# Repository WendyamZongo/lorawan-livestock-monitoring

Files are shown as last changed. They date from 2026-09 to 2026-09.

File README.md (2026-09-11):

# LoRaWAN Livestock Health and Location Monitoring System

An end-to-end LoRaWAN system for monitoring cattle body temperature and location, covering the ear-tag sensor node, the radio link, the gateway, and a real-time web dashboard.

The system is designed for extensive grazing conditions, where animals are dispersed over large areas with no cellular coverage and no mains power, and where a herder cannot practically inspect every animal every day. Early detection of a temperature anomaly and knowledge of an animal's position are the two pieces of information that matter most in that setting.

**Status:** functional prototype. All four subsystems are implemented and working end to end. See Limitations for what is not yet in place.

---
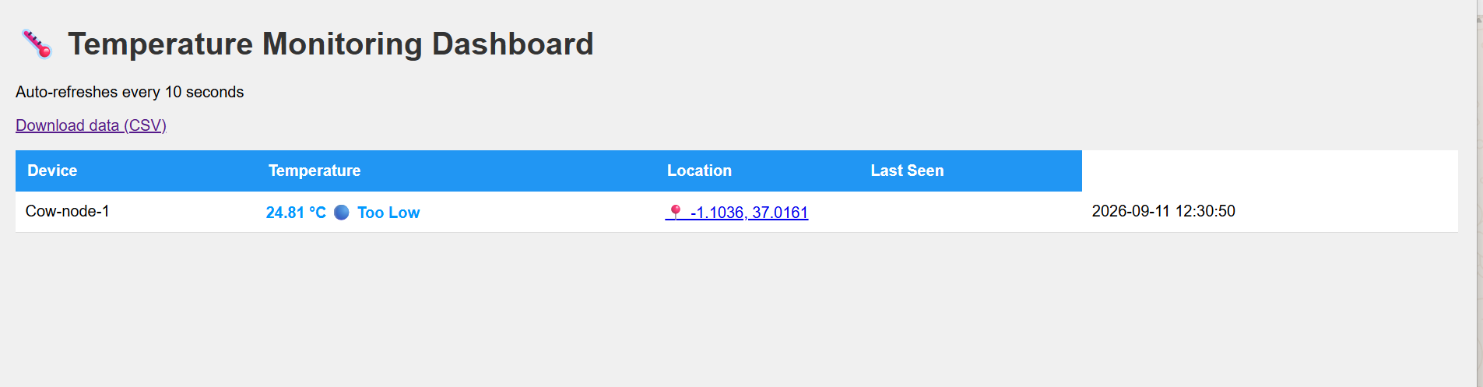
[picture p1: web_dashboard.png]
Dashboard


*Real-time herd monitoring dashboard*

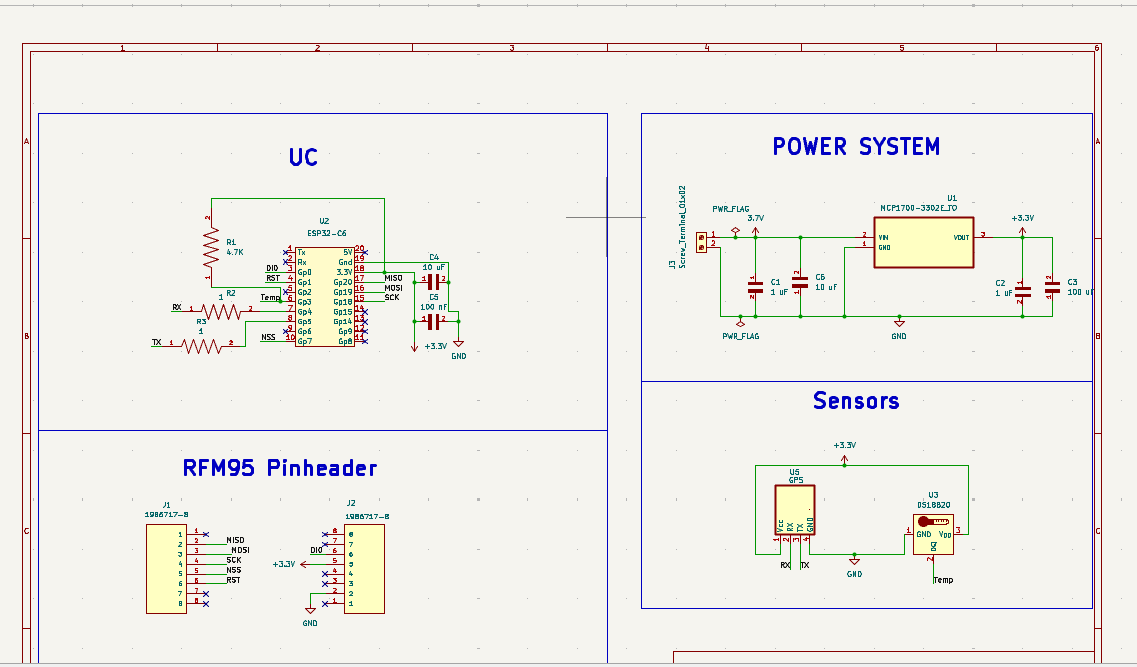
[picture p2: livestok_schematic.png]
Schematic


*Ear tag node schematic*

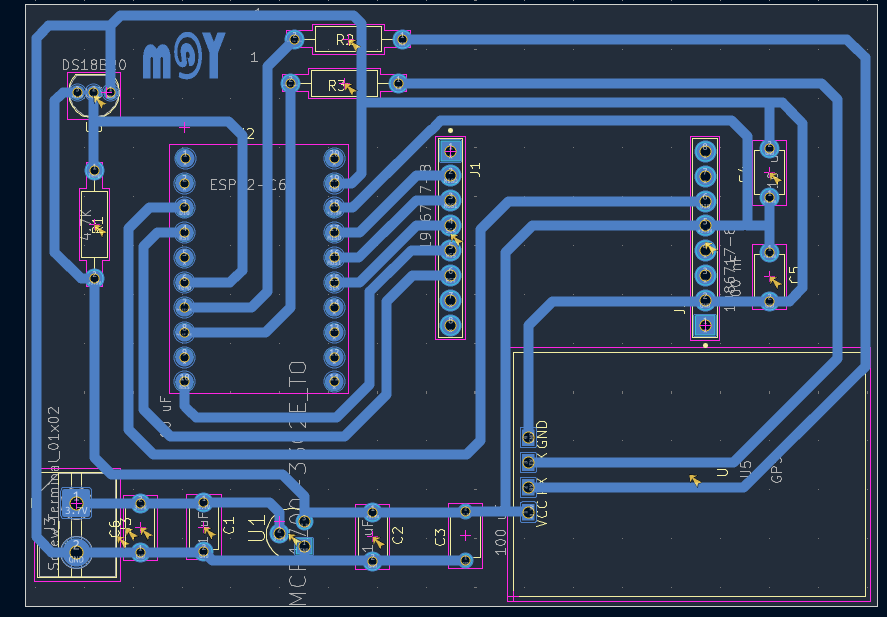
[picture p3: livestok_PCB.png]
PCB


*Ear tag node PCB layout*

## System architecture

```
  Ear tag node                    Gateway                    Server
  ------------                    -------                    ------
  ESP32-C6                                                   ChirpStack
  DS18B20  (temperature)   -->    RAK5146 PiHAT       -->    (self-hosted)
  NEO-6M   (GNSS)                 Raspberry Pi                    |
  RFM95W   (LoRa)                                             MQTT
  12,000 mAh Li-ion                                               |
                                                                  v
         LoRaWAN uplink, 4x per day                        Flask dashboard
                                                            + CSV logging
```

---

## Ear tag node

Battery-powered sensor node worn as an ear tag.

| Function | Part |
|---|---|
| MCU | ESP32-C6 |
| Body temperature | DS18B20 (1-Wire) |
| Localisation | u-blox NEO-6M GNSS |
| Radio | RFM95W (LoRa, 868 MHz, SF7) |
| Power | Single 12,000 mAh 3.7 V Li-ion cell |

Firmware is written in C++ using the Arduino framework.

The LoRaWAN ABP uplink path is implemented directly in the firmware, including AES-128 payload encryption and the CMAC-based message integrity check, rather than through a LoRaWAN stack library. This was done to work through the MAC layer explicitly. A production build would use an audited implementation.

### Operating cycle

The node spends almost all of its life in deep sleep. Four times per day it wakes, reads body temperature, acquires a GNSS fix, transmits a single LoRaWAN uplink, and returns to sleep.

Deep sleep on the ESP32-C6 clears RAM and restarts execution from the top, so the entire measurement cycle runs in `setup()` and `loop()` is unused. The LoRaWAN frame counter is held in RTC memory so that it survives sleep; without this the network server would reject every uplink as a replay.

The GNSS receiver is placed in UBX backup mode before sleeping rather than left running. Fix acquisition is bounded by a timeout, and the payload carries a validity flag so the decoder can distinguish a real position from a cycle that ended without a fix. A node under heavy tree cover therefore still reports its temperature instead of draining the cell waiting for satellites.

### Temperature interpretation

The dashboard currently classifies each reading against fixed thresholds: below 35 °C, normal to 38.5 °C, warning to 39.5 °C, and fever above that.

These thresholds are a placeholder, and the limits of the approach are worth stating. The DS18B20 is specified at ±0.5 °C, and an ear tag measures at a site exposed to solar radiation and wind. A fixed cut-off will therefore raise false fever alerts on a hot afternoon and miss real ones at night.

The intended replacement is alerting on sustained deviation from each animal's own baseline, which absorbs both the sensor offset and the individual animal. That logic is not yet implemented.

### Power budget

Sizing assumptions for the 12,000 mAh cell:

| Item | Estimate |
|---|---|
| GNSS fix | ~30 mA for 30 s per cycle |
| LoRa transmit (SF7, 24-byte frame) | ~100 mA for ~60 ms per cycle |
| Sensing and processing | ~40 mA for a few seconds per cycle |
| Deep sleep | board-level quiescent current |
| Cycles per day | 4 |

Transmission is negligible in this budget; the GNSS fix dominates the active cycle. Four cycles per day therefore consume only a few mAh, and on these assumptions the node supports well over two years of operation.

The dominant unknown is board-level quiescent current, not the active cycle. Measuring true sleep current on the assembled board is the single most useful validation step for this figure.

---

## Custom PCB

KiCad design files for the node, including the RFM95W transceiver front-end.

RF layout was the main constraint: ground plane continuity under the transceiver, trace impedance on the antenna feed, antenna placement relative to the enclosure and to the animal's body, and supply decoupling close to the module. The antenna is a soldered helical spring rather than a connectorised u.FL or SMA part, so its position is fixed at assembly and had to be planned around the rest of the layout.

A separate RFM95W breakout board was also designed and fabricated to adapt the module's 2 mm pin pitch to a standard 2.54 mm grid, for bench prototyping and node integration. It carries the module and its pin headers only, and is supplied with regulated 3.3 V from the host board.

Files are in `hardware/`.

---

## Gateway

- **RAK5146 PiHAT Kit** on a Raspberry Pi
- Forwards LoRaWAN uplinks to the network server

Configuration notes are in `gateway/`.

---

## Network server

**ChirpStack**, self-hosted. Handles device provisioning, session keys, deduplication of uplinks received by multiple gateways, and payload decoding.

The device payload decoder is in `chirpstack/`. The uplink carries body temperature, latitude, longitude, and a GNSS validity flag.

---

## Web application

A **Python / Flask** application subscribes to the ChirpStack MQTT broker on the uplink topic for the application, decodes each event, and serves a dashboard showing every device with its latest temperature, its last known position as a Google Maps link, and the time it was last heard from. The page refreshes on a timer, and temperature values are colour-coded by band.

Every uplink is appended to a CSV file, which is the historical record and the export path for offline analysis.

Source is in `webapp/`.

---

## Repository layout

```
firmware/
  Cow_monitoring.ino  ESP32-C6 node firmware (Arduino)
  secrets.h.example   template for LoRaWAN session keys
hardware/
  node/               KiCad schematic and PCB for the ear tag node
  rfm95-breakout/     KiCad files for the RFM95W pitch-adapter board
gateway/              Raspberry Pi + RAK5146 configuration
chirpstack/           payload decoder and device profile
webapp/               Flask dashboard and MQTT subscriber
```

Real LoRaWAN session keys live in `firmware/secrets.h`, which is gitignored. Copy `secrets.h.example` and fill in your own device keys from ChirpStack before flashing.

---

## Limitations

Stated plainly, because they matter to anyone considering this work.

- **Fixed temperature thresholds.** Alerting uses absolute cut-offs rather than a per-animal baseline, which is not adequate for an ear-tag measurement site. See Temperature interpretation above.
- **No database.** History lives in a CSV file. The dashboard itself holds only the latest reading per device in memory, so it is blank after a restart until the next uplink arrives, which may be six hours away.
- **No field validation against a reference.** Temperature readings have not been validated against a rectal or ruminal reference measurement on live animals, which is the standard against which any livestock temperature system must eventually be judged.
- **Battery life is calculated, not measured.** The two-year figure follows from the power budget above. It has not been confirmed by long-duration testing, and board-level sleep current has not yet been measured directly.
- **Hand-rolled cryptography.** The AES-128 and CMAC implementations are the author's own and have not been independently audited. They are appropriate for a prototype, not for a deployed product.
- **NEO-6M cold start.** The module is an older generation with slow cold-start acquisition. Retaining almanac data across wake cycles would reduce time to fix and further improve the energy margin.
- **Single-tag testing.** The system has not been exercised with a herd-scale number of nodes, so airtime contention and duty-cycle behaviour at scale remain untested.

---

## Next steps

- Measure board-level quiescent current and confirm the energy budget empirically
- Replace fixed thresholds with per-animal baseline tracking and deviation-based alerting
- Move from CSV to a time-series database, and reload the dashboard state on restart
- Validate temperature against a reference measurement on live animals
- Test with multiple nodes to characterise airtime and collision behaviour

---

## Author

Wendyam Clovis Dubois Zongo
MSc Electrical Engineering (Computer Engineering), PAUSTI / JKUAT, Nairobi
Embedded systems and FPGA engineer

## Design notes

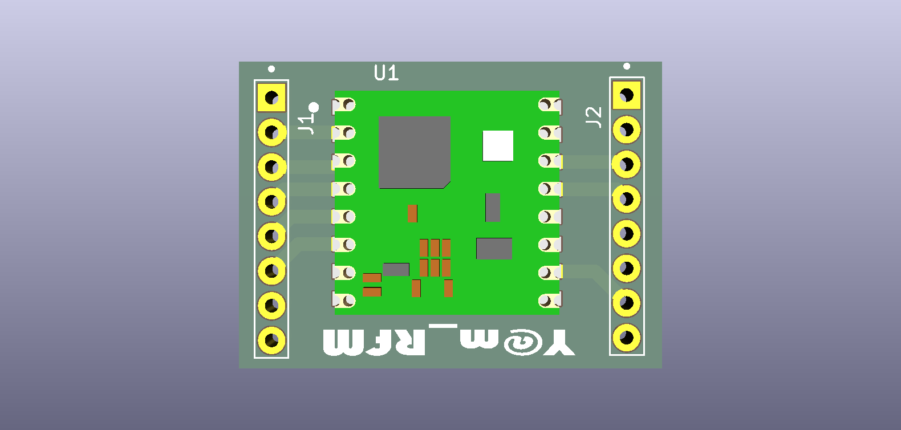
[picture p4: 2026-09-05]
hardware/RFM /RFM0.1.png

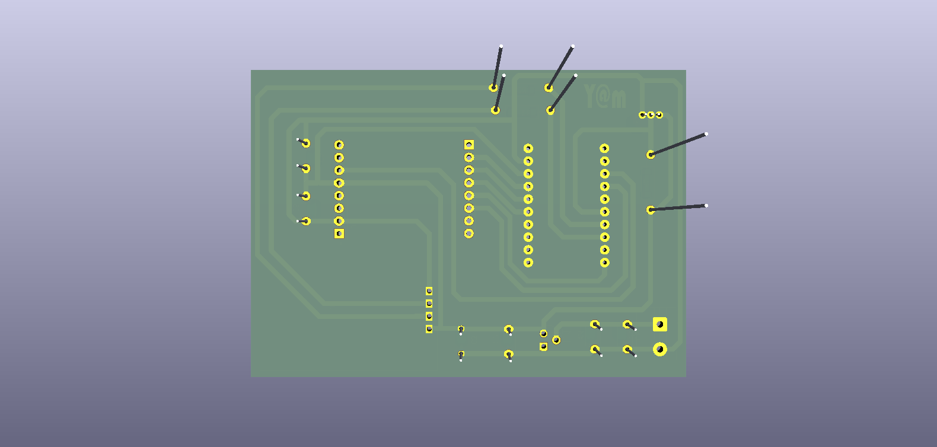
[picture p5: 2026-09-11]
livestok_.png

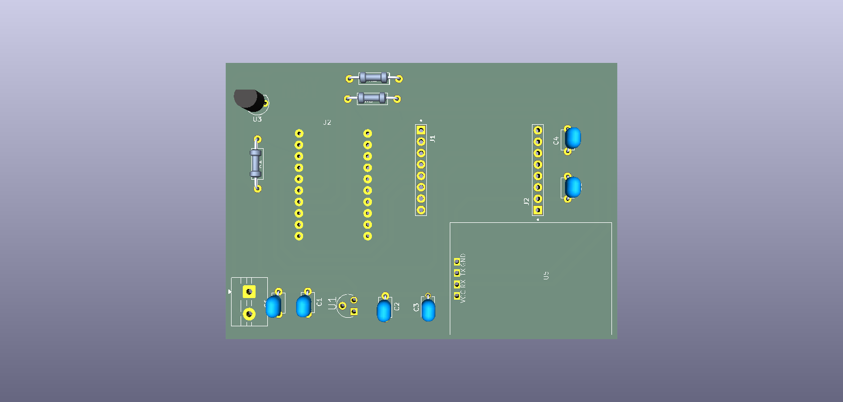
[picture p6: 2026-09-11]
livestok.png

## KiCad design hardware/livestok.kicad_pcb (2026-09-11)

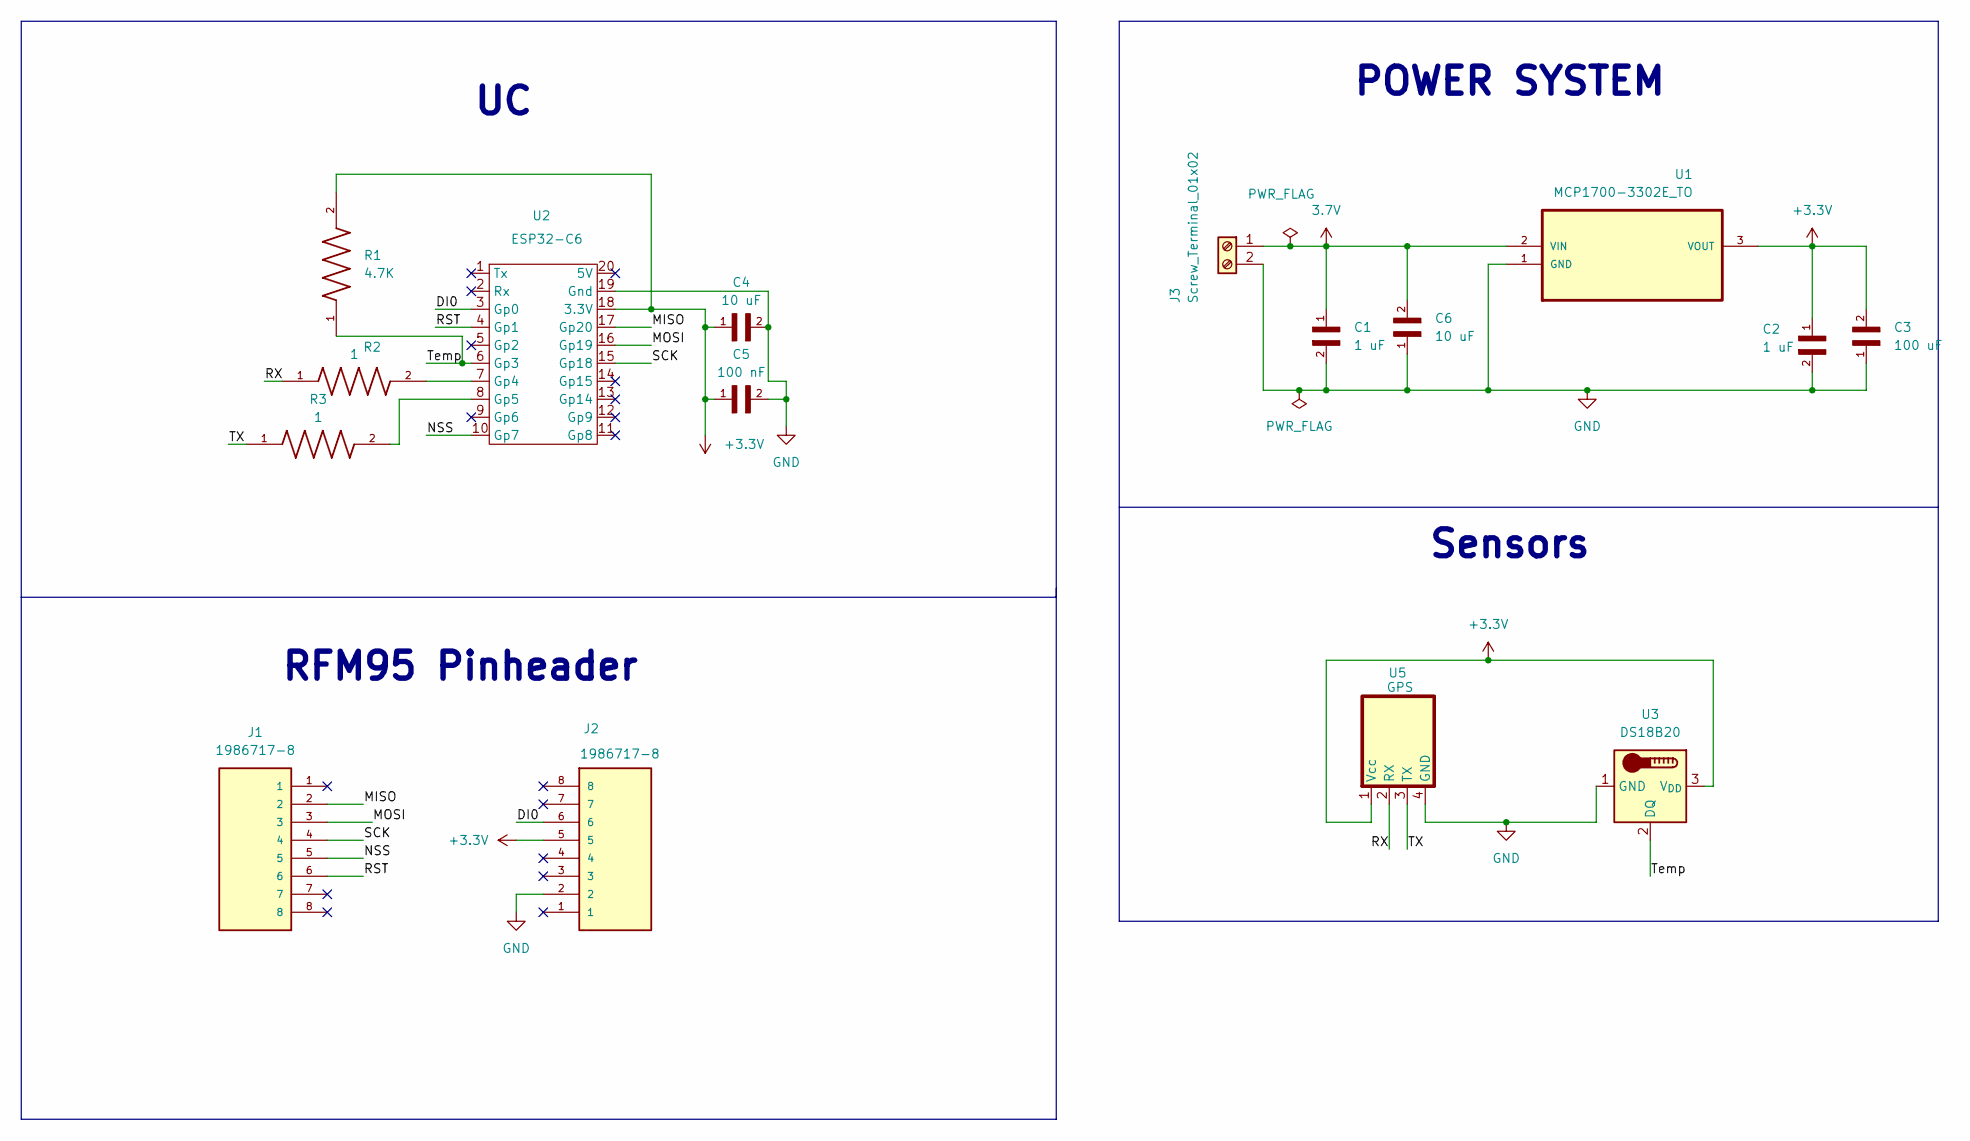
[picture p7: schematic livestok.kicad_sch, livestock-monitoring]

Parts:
C1, C2: 1 uF; CAPRB500W50L450T300H550; PARTREV 20200310
C3: 100 uF; CAPRB500W50L450T300H550; PARTREV 20200310
C4, C6: 10 uF; CAPRB500W50L450T300H550; PARTREV 20200310
C5: 100 nF; CAPRB500W50L450T300H550; PARTREV 20200310
J1, J2: 1986717-8; TE_826629-8; PARTREV R
J3: Screw_Terminal_01x02; TerminalBlock_MaiXu_MX126-5.0-02P_1x02_P5.00mm
R1: 4.7K; RESAD1100W55L680D260; PARTREV 201304
R2, R3: 1; RESAD1100W55L680D260; PARTREV 201304
U1: MCP1700-3302E_TO; TO127P254X495-3; MPN MCP1700-3302E/TO
U2: ESP32-C6; C6-mini
U3: DS18B20; TO-92_Inline
U5: GPS; Gps_Yam

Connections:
3.7V: C1.1, C6.2, J3.1, U1.2 (VIN)
+3.3V: C2.1, C3.2, C4.1, C5.1, J2.5, R1.2, U1.3 (VOUT), U2.18 (3.3V), U3.3 (V_{DD}), U5.1 (Vcc)
/DI0: J2.6, U2.3 (Gp0)
/MISO: J1.2, U2.17 (Gp20)
/MOSI: J1.3, U2.16 (Gp19)
/NSS: J1.5, U2.10 (Gp7)
/RST: J1.6, U2.4 (Gp1)
/RX: R2.1, U5.2 (RX)
/SCK: J1.4, U2.15 (Gp18)
/TX: R3.1, U5.3 (TX)
/Temp: R1.1, U2.6 (Gp3), U3.2 (DQ)
GND: C1.2, C2.2, C3.1, C4.2, C5.2, C6.1, J2.2, J3.2, U1.1 (GND), U2.19 (Gnd), U3.1 (GND), U5.4 (GND)
unnamed: R2.2, U2.7 (Gp4)
unnamed: R3.2, U2.8 (Gp5)

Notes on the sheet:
RFM95 Pinheader
POWER SYSTEM
Sensors

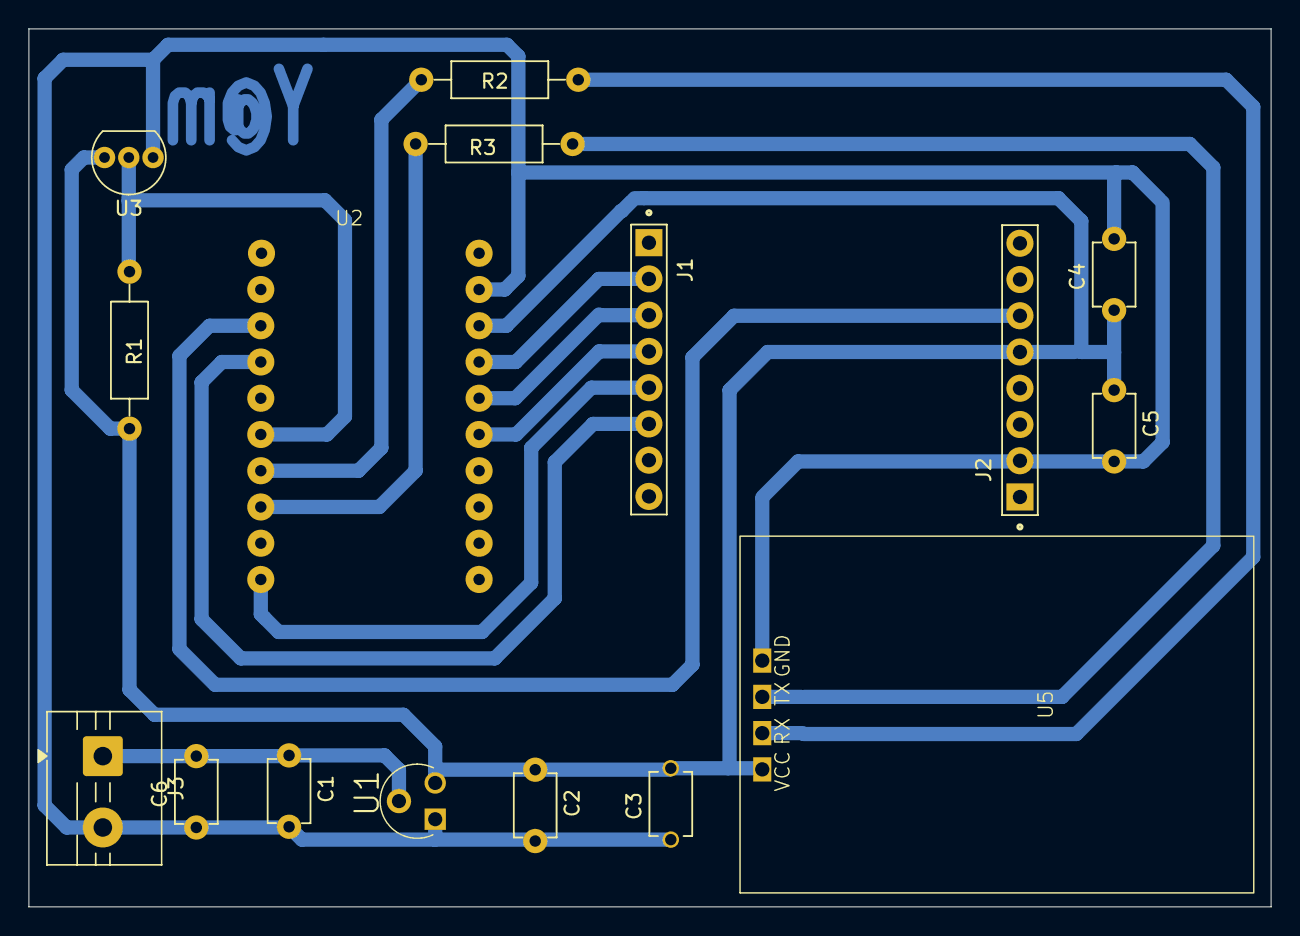
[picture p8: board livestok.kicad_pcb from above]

Board: 2 copper layers, 87.1 x 61.5 mm, 16 parts (0 on the bottom side), 14 nets.

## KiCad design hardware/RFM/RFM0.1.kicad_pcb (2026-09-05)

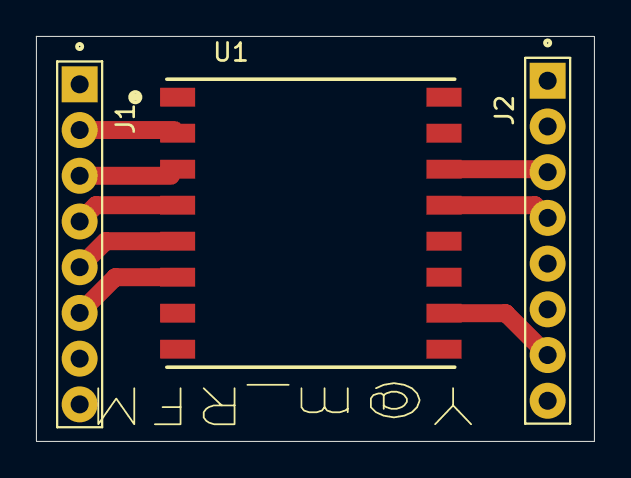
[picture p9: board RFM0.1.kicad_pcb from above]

Board: 2 copper layers, 31.0 x 22.5 mm, 3 parts (0 on the bottom side), 8 nets.

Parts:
J1, J2: 826629-8; TE_826629-8
U1: RFM95W-868S2; XCVR_RFM95W-868S2

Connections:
/DIO: J2.3, U1.14 (DIO0)
/GND: J2.7, U1.10 (GND@2)
/MOSI: J1.3, U1.3 (MOSI)
unnamed: J1.2, U1.2 (MISO)
unnamed: J1.4, U1.4 (SCK)
unnamed: J1.5, U1.5 (NSS)
unnamed: J1.6, U1.6 (RESET)
unnamed: J2.4, U1.13 (3_3V)

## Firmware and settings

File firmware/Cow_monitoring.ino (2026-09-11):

/**
 * LoRaWAN Cattle Health Monitoring Firmware
 *
 * Hardware : ESP32-C6 Super Mini (Cezerio)
 * Sensors  : DS18B20 (temperature) + NEO-6M (GPS)
 * Radio    : RFM95W 868MHz (LoRaWAN ABP EU868)
 *
 * Power strategy:
 *   The node wakes 4 times per day, acquires a GPS fix, reads body
 *   temperature, transmits one LoRaWAN uplink, then returns to deep sleep.
 *   The GPS receiver is placed in UBX backup mode before sleeping.
 *   Frame counter is held in RTC memory so it survives deep sleep.
 *
 * Pin Configuration:
 * RFM95 SCK  -> GP18
 * RFM95 MISO -> GP20
 * RFM95 MOSI -> GP19
 * RFM95 NSS  -> GP7
 * RFM95 RST  -> GP1
 * RFM95 DIO0 -> GP0
 * DS18B20    -> GP3 (+ 4.7k pull-up to 3V3)
 * GPS TX     -> GP4
 * GPS RX     -> GP5
 *
 * Author: Wendyam Clovis Dubois Zongo
 * License: MIT
 */

#include <SPI.h>
#include <RadioLib.h>
#include <DS18B20.h>
#include <HardwareSerial.h>
#include <TinyGPS++.h>
#include <esp_sleep.h>

// --- PIN DEFINITIONS -----------------------------------------
#define DS18B20_PIN  3
#define RFM95_NSS    7
#define RFM95_RST    1
#define RFM95_DIO0   0
#define RFM95_SCK    18
#define RFM95_MISO   20
#define RFM95_MOSI   19
#define GPS_RX_PIN   4   // GPS TX connects here
#define GPS_TX_PIN   5   // GPS RX connects here

// --- POWER / TIMING CONFIGURATION ----------------------------
// Set TEST_MODE to 1 for bench testing: one cycle per minute instead
// of one every six hours, so the sleep and wake path can be observed.
// Set back to 0 before deploying.
#define TEST_MODE 0

#if TEST_MODE
  #define SLEEP_SECONDS     60UL
#else
  // 4 uplinks per day -> one cycle every 6 hours
  #define SLEEP_SECONDS     (6UL * 60UL * 60UL)
 
#endif

#define uS_PER_S            1000000ULL

// How long we are willing to wait for a GPS fix before giving up.
// Longer means better fix rate, shorter means less energy per cycle.
#define GPS_FIX_TIMEOUT_MS  180000UL

// Set to 1 if a MOSFET cuts the GPS supply from a GPIO.
// Set to 0 to rely on UBX backup mode only (no hardware change needed).
#define GPS_HARD_POWER_GATE 0
#if GPS_HARD_POWER_GATE
  #define GPS_EN_PIN 2
#endif

// UBX backup mode cuts GPS current to ~11 uA during sleep, but some
// NEO-6M modules do not resume from it reliably. Set to 0 to leave the
// receiver running: this costs battery life but rules the backup path
// out as a cause when the module stops producing NMEA.
#define GPS_BACKUP_MODE 1

// Set to 1 to echo raw NMEA sentences to the serial monitor while
// waiting for a fix. Use it to confirm the module is talking at all.
#define GPS_DEBUG_NMEA 0

// --- DS18B20 -------------------------------------------------
DS18B20 sensor(DS18B20_PIN);

// A 12-bit conversion takes 750 ms. Reading before it completes returns
// the sensor's power-on scratchpad value of exactly 85.00 C, which is
// not a measurement. Any reading at or above this bound is rejected.
#define DS18B20_INVALID_HIGH   84.0
#define DS18B20_INVALID_LOW   -50.0
#define DS18B20_CONV_MS        800UL
#define DS18B20_ATTEMPTS       3

// --- GPS -----------------------------------------------------
HardwareSerial gpsSerial(1);
TinyGPSPlus gps;

// --- LORA ----------------------------------------------------
RFM95 radio = new Module(RFM95_NSS, RFM95_DIO0, RFM95_RST);

// --- ABP KEYS ------------------------------------------------
// Replace with your own ChirpStack ABP session keys.
// Never commit real keys to a public repository.
uint8_t NwkSKey[16] = {
  0x00, 0x00, 0x00, 0x00, 0x00, 0x00, 0x00, 0x00,
  0x00, 0x00, 0x00, 0x00, 0x00, 0x00, 0x00, 0x00
};
uint8_t AppSKey[16] = {
  0x00, 0x00, 0x00, 0x00, 0x00, 0x00, 0x00, 0x00,
  0x00, 0x00, 0x00, 0x00, 0x00, 0x00, 0x00, 0x00
};
uint32_t DevAddr = 0x00000000;


// Frame counter must persist across deep sleep, otherwise the network
// server rejects uplinks as replays. RTC_DATA_ATTR keeps it in RTC RAM,
// which stays powered while the main core is off.
RTC_DATA_ATTR uint16_t frameCounter = 0;
RTC_DATA_ATTR uint32_t bootCount    = 0;

// --- AES-128 S-BOX -------------------------------------------
const uint8_t sbox[256] = {
  0x63,0x7c,0x77,0x7b,0xf2,0x6b,0x6f,0xc5,0x30,0x01,0x67,0x2b,0xfe,0xd7,0xab,0x76,
  0xca,0x82,0xc9,0x7d,0xfa,0x59,0x47,0xf0,0xad,0xd4,0xa2,0xaf,0x9c,0xa4,0x72,0xc0,
  0xb7,0xfd,0x93,0x26,0x36,0x3f,0xf7,0xcc,0x34,0xa5,0xe5,0xf1,0x71,0xd8,0x31,0x15,
  0x04,0xc7,0x23,0xc3,0x18,0x96,0x05,0x9a,0x07,0x12,0x80,0xe2,0xeb,0x27,0xb2,0x75,
  0x09,0x83,0x2c,0x1a,0x1b,0x6e,0x5a,0xa0,0x52,0x3b,0xd6,0xb3,0x29,0xe3,0x2f,0x84,
  0x53,0xd1,0x00,0xed,0x20,0xfc,0xb1,0x5b,0x6a,0xcb,0xbe,0x39,0x4a,0x4c,0x58,0xcf,
  0xd0,0xef,0xaa,0xfb,0x43,0x4d,0x33,0x85,0x45,0xf9,0x02,0x7f,0x50,0x3c,0x9f,0xa8,
  0x51,0xa3,0x40,0x8f,0x92,0x9d,0x38,0xf5,0xbc,0xb6,0xda,0x21,0x10,0xff,0xf3,0xd2,
  0xcd,0x0c,0x13,0xec,0x5f,0x97,0x44,0x17,0xc4,0xa7,0x7e,0x3d,0x64,0x5d,0x19,0x73,
  0x60,0x81,0x4f,0xdc,0x22,0x2a,0x90,0x88,0x46,0xee,0xb8,0x14,0xde,0x5e,0x0b,0xdb,
  0xe0,0x32,0x3a,0x0a,0x49,0x06,0x24,0x5c,0xc2,0xd3,0xac,0x62,0x91,0x95,0xe4,0x79,
  0xe7,0xc8,0x37,0x6d,0x8d,0xd5,0x4e,0xa9,0x6c,0x56,0xf4,0xea,0x65,0x7a,0xae,0x08,
  0xba,0x78,0x25,0x2e,0x1c,0xa6,0xb4,0xc6,0xe8,0xdd,0x74,0x1f,0x4b,0xbd,0x8b,0x8a,
  0x70,0x3e,0xb5,0x66,0x48,0x03,0xf6,0x0e,0x61,0x35,0x57,0xb9,0x86,0xc1,0x1d,0x9e,
  0xe1,0xf8,0x98,0x11,0x69,0xd9,0x8e,0x94,0x9b,0x1e,0x87,0xe9,0xce,0x55,0x28,0xdf,
  0x8c,0xa1,0x89,0x0d,0xbf,0xe6,0x42,0x68,0x41,0x99,0x2d,0x0f,0xb0,0x54,0xbb,0x16
};

// --- AES HELPER FUNCTIONS ------------------------------------
uint8_t gmul(uint8_t a, uint8_t b) {
  uint8_t p = 0;
  for (int i = 0; i < 8; i++) {
    if (b & 1) p ^= a;
    bool hbs = a & 0x80;
    a <<= 1;
    if (hbs) a ^= 0x1b;
    b >>= 1;
  }
  return p;
}

void aes128_encrypt(uint8_t* key, uint8_t* in, uint8_t* out) {
  uint8_t state[16], w[176];
  memcpy(state, in, 16);
  memcpy(w, key, 16);
  const uint8_t rcon[10] = {0x01,0x02,0x04,0x08,0x10,0x20,0x40,0x80,0x1b,0x36};
  for (int i=4;i<44;i++) {
    uint8_t tmp[4];
    memcpy(tmp,w+(i-1)*4,4);
    if (i%4==0) {
      uint8_t t=tmp[0];
      tmp[0]=sbox[tmp[1]]^rcon[i/4-1];
      tmp[1]=sbox[tmp[2]];
      tmp[2]=sbox[tmp[3]];
      tmp[3]=sbox[t];
    }
    for (int j=0;j<4;j++) w[i*4+j]=w[(i-4)*4+j]^tmp[j];
  }
  for (int i=0;i<16;i++) state[i]^=w[i];
  for (int round=1;round<=10;round++) {
    for (int i=0;i<16;i++) state[i]=sbox[state[i]];
    uint8_t tmp;
    tmp=state[1]; state[1]=state[5]; state[5]=state[9]; state[9]=state[13]; state[13]=tmp;
    tmp=state[2]; state[2]=state[10]; state[10]=tmp;
    tmp=state[6]; state[6]=state[14]; state[14]=tmp;
    tmp=state[3]; state[3]=state[15]; state[15]=state[11]; state[11]=state[7]; state[7]=tmp;
    if (round<10) {
      for (int c=0;c<4;c++) {
        uint8_t s0=state[4*c],s1=state[4*c+1],s2=state[4*c+2],s3=state[4*c+3];
        state[4*c]   = gmul(s0,2)^gmul(s1,3)^s2^s3;
        state[4*c+1] = s0^gmul(s1,2)^gmul(s2,3)^s3;
        state[4*c+2] = s0^s1^gmul(s2,2)^gmul(s3,3);
        state[4*c+3] = gmul(s0,3)^s1^s2^gmul(s3,2);
      }
    }
    for (int i=0;i<16;i++) state[i]^=w[round*16+i];
  }
  memcpy(out,state,16);
}

void xor16(uint8_t* a, uint8_t* b, uint8_t* out) {
  for (int i=0;i<16;i++) out[i]=a[i]^b[i];
}

void computeMIC(uint8_t* msg, uint8_t msgLen, uint8_t* mic) {
  uint8_t b0[16] = {
    0x49,0x00,0x00,0x00,0x00,0x00,
    (uint8_t)(DevAddr),(uint8_t)(DevAddr>>8),
    (uint8_t)(DevAddr>>16),(uint8_t)(DevAddr>>24),
    (uint8_t)(frameCounter),(uint8_t)(frameCounter>>8),
    0x00,0x00,0x00,(uint8_t)msgLen
  };
  uint8_t K1[16]={0},K2[16]={0},L[16]={0},tmp[16]={0};
  aes128_encrypt(NwkSKey,tmp,L);
  bool msb=L[0]&0x80;
  for (int i=0;i<15;i++) K1[i]=(L[i]<<1)|(L[i+1]>>7);
  K1[15]=(L[15]<<1)^(msb?0x87:0x00);
  msb=K1[0]&0x80;
  for (int i=0;i<15;i++) K2[i]=(K1[i]<<1)|(K1[i+1]>>7);
  K2[15]=(K1[15]<<1)^(msb?0x87:0x00);
  uint8_t buf[64]={0};
  memcpy(buf,b0,16);
  memcpy(buf+16,msg,msgLen);
  int totalLen=16+msgLen;
  int nBlocks=(totalLen+15)/16;
  uint8_t X[16]={0},Y[16],last[16]={0};
  for (int i=0;i<nBlocks-1;i++) {
    xor16(X,buf+i*16,Y);
    aes128_encrypt(NwkSKey,Y,X);
  }
  int lastLen=totalLen%16;
  if (lastLen==0) lastLen=16;
  memcpy(last,buf+(nBlocks-1)*16,lastLen);
  if (lastLen==16) xor16(last,K1,last);
  else { last[lastLen]=0x80; xor16(last,K2,last); }
  xor16(X,last,Y);
  aes128_encrypt(NwkSKey,Y,X);
  memcpy(mic,X,4);
}

void encryptPayload(uint8_t* payload, uint8_t len, uint8_t* encrypted) {
  uint8_t A[16] = {
    0x01,0x00,0x00,0x00,0x00,0x00,
    (uint8_t)(DevAddr),(uint8_t)(DevAddr>>8),
    (uint8_t)(DevAddr>>16),(uint8_t)(DevAddr>>24),
    (uint8_t)(frameCounter),(uint8_t)(frameCounter>>8),
    0x00,0x00,0x00,0x01
  };
  uint8_t S[16];
  aes128_encrypt(AppSKey,A,S);
  for (int i=0;i<len;i++) encrypted[i]=payload[i]^S[i];
}

// --- SEND LORAWAN PACKET -------------------------------------
void sendLoRa(float tempC, int32_t lat, int32_t lon, bool gpsValid) {
  int16_t tempInt = (int16_t)(tempC * 100);

  // Byte 10 is a status flag so the decoder can tell a real fix
  // from a cycle that timed out without one.
  uint8_t plainPayload[11];
  plainPayload[0] = (tempInt >> 8) & 0xFF;
  plainPayload[1] =  tempInt & 0xFF;
  plainPayload[2] = (lat >> 24) & 0xFF;
  plainPayload[3] = (lat >> 16) & 0xFF;
  plainPayload[4] = (lat >> 8) & 0xFF;
  plainPayload[5] =  lat & 0xFF;
  plainPayload[6] = (lon >> 24) & 0xFF;
  plainPayload[7] = (lon >> 16) & 0xFF;
  plainPayload[8] = (lon >> 8) & 0xFF;
  plainPayload[9] =  lon & 0xFF;
  plainPayload[10] = gpsValid ? 0x01 : 0x00;

  uint8_t encPayload[11];
  encryptPayload(plainPayload, 11, encPayload);

  uint8_t msg[20];
  msg[0] = 0x40;
  msg[1] = DevAddr & 0xFF;
  msg[2] = (DevAddr >> 8) & 0xFF;
  msg[3] = (DevAddr >> 16) & 0xFF;
  msg[4] = (DevAddr >> 24) & 0xFF;
  msg[5] = 0x00;
  msg[6] = frameCounter & 0xFF;
  msg[7] = (frameCounter >> 8) & 0xFF;
  msg[8] = 0x01;
  memcpy(msg + 9, encPayload, 11);

  uint8_t mic[4];
  computeMIC(msg, 20, mic);

  uint8_t packet[24];
  memcpy(packet, msg, 20);
  memcpy(packet + 20, mic, 4);

  radio.transmit(packet, 24);
  frameCounter++;
}

// --- TEMPERATURE ---------------------------------------------
// Reads the DS18B20, rejecting the 85.00 C power-on default that comes
// back when the conversion has not completed. Returns -99.0 on failure,
// which the payload decoder treats as a sensor fault.
float readTemperature() {
  for (int attempt = 0; attempt < DS18B20_ATTEMPTS; attempt++) {
    float t = sensor.getTempC();

    if (!isnan(t) && t < DS18B20_INVALID_HIGH && t > DS18B20_INVALID_LOW) {
      return t;
    }

    Serial.print("DS18B20: invalid reading (");
    Serial.print(t);
    Serial.println("), retrying");
    delay(DS18B20_CONV_MS);
  }
  return -99.0;
}

// --- GPS POWER MANAGEMENT ------------------------------------

// UBX-RXM-PMREQ: put the NEO-6M into backup mode indefinitely.
// Draws roughly 11 uA instead of tens of mA, and retains almanac and
// ephemeris on boards with a V_BCKP supply, giving hot starts on wake.
void gpsEnterBackup() {
#if GPS_BACKUP_MODE
  const uint8_t pmreq[] = {
    0xB5, 0x62, 0x02, 0x41, 0x08, 0x00,
    0x00, 0x00, 0x00, 0x00,   // duration 0 = infinite
    0x02, 0x00, 0x00, 0x00,   // flags: backup
    0x4D, 0x3B                // checksum
  };
  gpsSerial.write(pmreq, sizeof(pmreq));
  gpsSerial.flush();
  delay(50);
#endif

#if GPS_HARD_POWER_GATE
  digitalWrite(GPS_EN_PIN, LOW);
#endif
}

void gpsWake() {
#if GPS_HARD_POWER_GATE
  pinMode(GPS_EN_PIN, OUTPUT);
  digitalWrite(GPS_EN_PIN, HIGH);
  delay(200);
#endif

#if GPS_BACKUP_MODE
  // A single byte is not always enough. Some NEO-6M modules need
  // sustained UART traffic and a longer settling delay before they
  // leave backup mode and resume producing NMEA output.
  for (int i = 0; i < 20; i++) {
    gpsSerial.write(0xFF);
  }
  gpsSerial.flush();
  delay(500);
#endif
}

// Wait for a valid fix, or give up after GPS_FIX_TIMEOUT_MS.
// Returns true if a fix was obtained.
bool acquireGpsFix(int32_t &lat, int32_t &lon) {
  uint32_t start = millis();
  while (millis() - start < GPS_FIX_TIMEOUT_MS) {
    while (gpsSerial.available() > 0) {
      char c = gpsSerial.read();
      gps.encode(c);
#if GPS_DEBUG_NMEA
      Serial.write(c);
#endif
    }
    if (gps.location.isValid() && gps.location.age() < 2000) {
      lat = (int32_t)(gps.location.lat() * 10000);
      lon = (int32_t)(gps.location.lng() * 10000);
      return true;
    }
    delay(10);
  }
  lat = 0;
  lon = 0;
  return false;
}

// --- ENTER DEEP SLEEP ----------------------------------------
void goToSleep() {
  gpsEnterBackup();

  // Put the radio in its lowest power state before the MCU sleeps.
  radio.sleep();

  // Release SPI so the pins do not hold current paths open.
  SPI.end();

  Serial.print("Sleeping for ");
  Serial.print(SLEEP_SECONDS);
  Serial.println(" s");
  Serial.flush();

  esp_sleep_enable_timer_wakeup(SLEEP_SECONDS * uS_PER_S);
  esp_deep_sleep_start();
  // Execution never returns here. The next wake restarts from setup().
}

// --- SETUP ---------------------------------------------------
// With deep sleep, every wake-up re-runs setup() from the top.
// The whole measurement cycle therefore lives here, and loop() is unused.
void setup() {
  bootCount++;

  Serial.begin(115200);
  delay(50);
  Serial.print("=== ESP32-C6 Cow Monitoring | cycle ");
  Serial.print(bootCount);
  Serial.print(" | fcnt ");
  Serial.println(frameCounter);

  // --- GPS ---
  // Started first so the receiver begins acquiring while the radio and
  // the temperature sensor are being brought up.
  gpsSerial.begin(9600, SERIAL_8N1, GPS_RX_PIN, GPS_TX_PIN);
  gpsWake();

  // --- SPI + RFM95 ---
  SPI.begin(RFM95_SCK, RFM95_MISO, RFM95_MOSI, RFM95_NSS);

  pinMode(RFM95_RST, OUTPUT);
  digitalWrite(RFM95_RST, LOW);
  delay(10);
  digitalWrite(RFM95_RST, HIGH);
  delay(10);

  int state = radio.begin(868.1);
  if (state != RADIOLIB_ERR_NONE) {
    Serial.print("LoRa init failed, error ");
    Serial.println(state);
    // Do not spin forever on a battery node. Sleep and retry next cycle.
    goToSleep();
  }

  radio.setSyncWord(0x34);
  radio.setCRC(true);
  radio.setSpreadingFactor(7);
  radio.setBandwidth(125.0);
  radio.setCodingRate(5);

  // --- Temperature ---
  float tempC = readTemperature();
  if (tempC < -90.0) {
    Serial.println("DS18B20 fault, sending sentinel value");
  } else {
    Serial.print("Temperature: ");
    Serial.print(tempC);
    Serial.println(" C");
  }

  // --- GPS fix ---
  int32_t lat = 0, lon = 0;
  bool gpsValid = acquireGpsFix(lat, lon);
  if (gpsValid) {
    Serial.print("GPS fix: ");
    Serial.print(gps.location.lat(), 6);
    Serial.print(", ");
    Serial.println(gps.location.lng(), 6);
  } else {
    Serial.println("GPS: no fix within timeout");
  }

  // --- Transmit ---
  sendLoRa(tempC, lat, lon, gpsValid);
  Serial.print("Uplink sent, next fcnt ");
  Serial.println(frameCounter);

  // --- Sleep ---
  goToSleep();
}

// Never reached: the node always sleeps at the end of setup().
void loop() {
}

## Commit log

2026-09-05 Rename RFM0.1.kicad_pro to hardware/RFM /RFM0.1.kicad_pro
2026-09-05 Rename RFM0.1.kicad_sch to hardware/RFM /RFM0.1.kicad_sch
    [RFM0.1.kicad_sch]
